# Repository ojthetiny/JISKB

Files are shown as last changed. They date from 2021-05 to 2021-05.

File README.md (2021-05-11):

# JISKB

Layout by the ever so wonderful Tesla

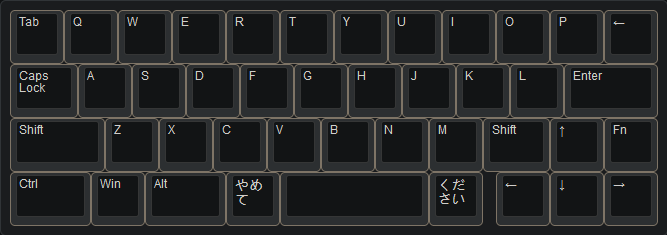
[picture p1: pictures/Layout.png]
Layout by the ever so wonderful Tesla


don't ask me what the fuck this is or why it exists, not my idea.
it's a jis hhkb 35% board or something, I was bored OK

pics of the fancy routing or whatever
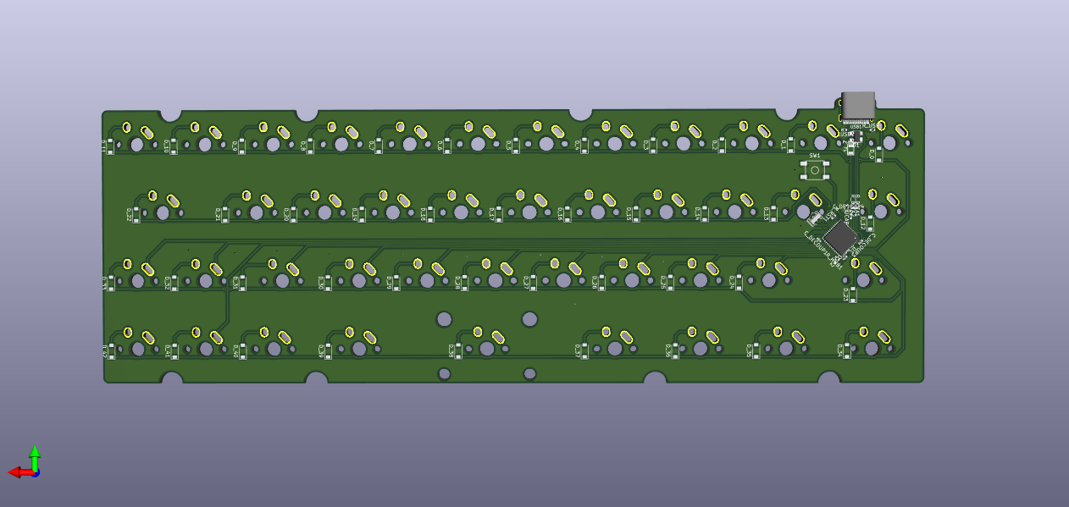
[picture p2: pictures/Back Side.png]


pics of the front if you give a shit, you probably don't
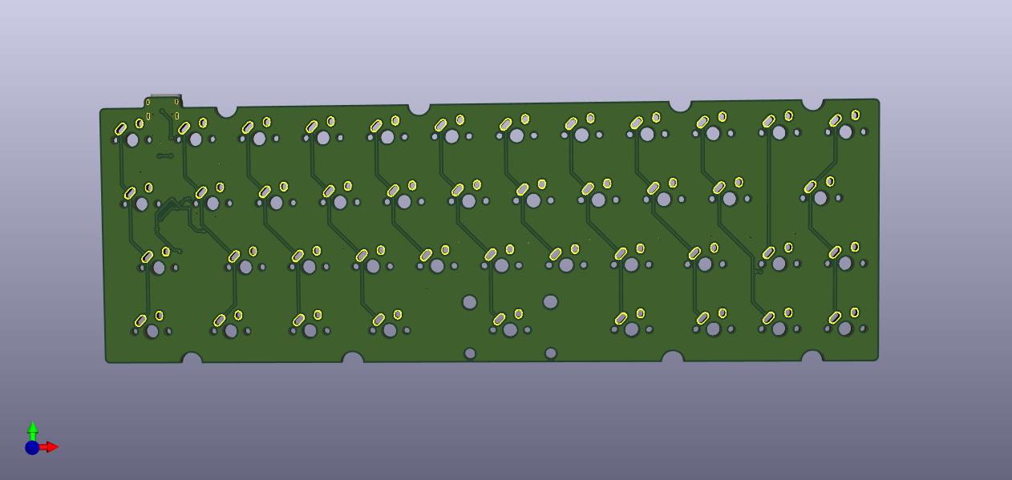
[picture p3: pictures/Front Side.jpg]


All the files are in the folders, including bom and pos files for assembly by jlc. if you wanna get this made you look for them yourself, I'm not helping you, use your noggin'

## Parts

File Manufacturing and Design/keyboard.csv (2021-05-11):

Comment | Designator | Footprint | LCSC
.1u | C_DECOUP1,C_DECOUP2,C_DECOUP3 | Capacitor_SMD:C_0402_1005Metric | C1525
10u | C_DECOUP4 | Capacitor_SMD:C_0402_1005Metric | C15525
1u | C_UCAP1 | Capacitor_SMD:C_0402_1005Metric | C107372
PRTR5V0U2X | D1 | Package_TO_SOT_SMD:SOT-143 | C12333
D | D_0,D_1,D_2,D_3,D_4,D_5,D_6,D_7,D_8,D_9,D_10,D_11,D_12,D_13,D_14,D_15,D_16,D_17,D_18,D_19,D_20,D_21,D_22,D_23,D_24,D_25,D_26,D_27,D_28,D_29,D_30,D_31,D_32,D_33,D_34,D_35,D_36,D_37,D_38,D_39,D_40,D_41,D_42 | Diode_SMD:D_SOD-123 | C64898
Polyfuse | F1 | Components:Fuse_0805 | C261942
KEYSW | K_0,K_1,K_2,K_3,K_4,K_5,K_6,K_7,K_8,K_9,K_10,K_11,K_13,K_14,K_15,K_16,K_17,K_18,K_19,K_20,K_21,K_24,K_25,K_26,K_27,K_28,K_29,K_30,K_32,K_33,K_35,K_37,K_39,K_40,K_41,K_42 | MX_Alps_Hybrid:MX-1U-NoLED
KEYSW | K_12,K_31 | MX_Alps_Hybrid:MX-1.25U-NoLED
KEYSW | K_22,K_23 | MX_Alps_Hybrid:MX-1.75U-NoLED
KEYSW | K_34,K_36 | MX_Alps_Hybrid:MX-1.5U-NoLED
KEYSW | K_38 | MX_Alps_Hybrid:MX-2.75U-NoLED
22 | R_DATA1,R_DATA2 | Resistor_SMD:R_0402_1005Metric | C25092
10k | R_HWB1,R_RST1 | Resistor_SMD:R_0402_1005Metric | C25744
5k1 | R_USB1,R_USB2 | Resistor_SMD:R_0402_1005Metric | C25905
SW_Push | SW1 | Components:SKQG-1155865
ATmega32U4-M | U1 | Package_DFN_QFN:QFN-44-1EP_7x7mm_P0.5mm_EP5.2x5.2mm | C112161
HRO-TYPE-C-31-M-12 | USB1 | Components:HRO-TYPE-C-31-M-12-Assembly | C165948
Resonator_Small | Y1 | Crystal:Resonator_SMD_Murata_CSTxExxV-3Pin_3.0x1.1mm | C341521

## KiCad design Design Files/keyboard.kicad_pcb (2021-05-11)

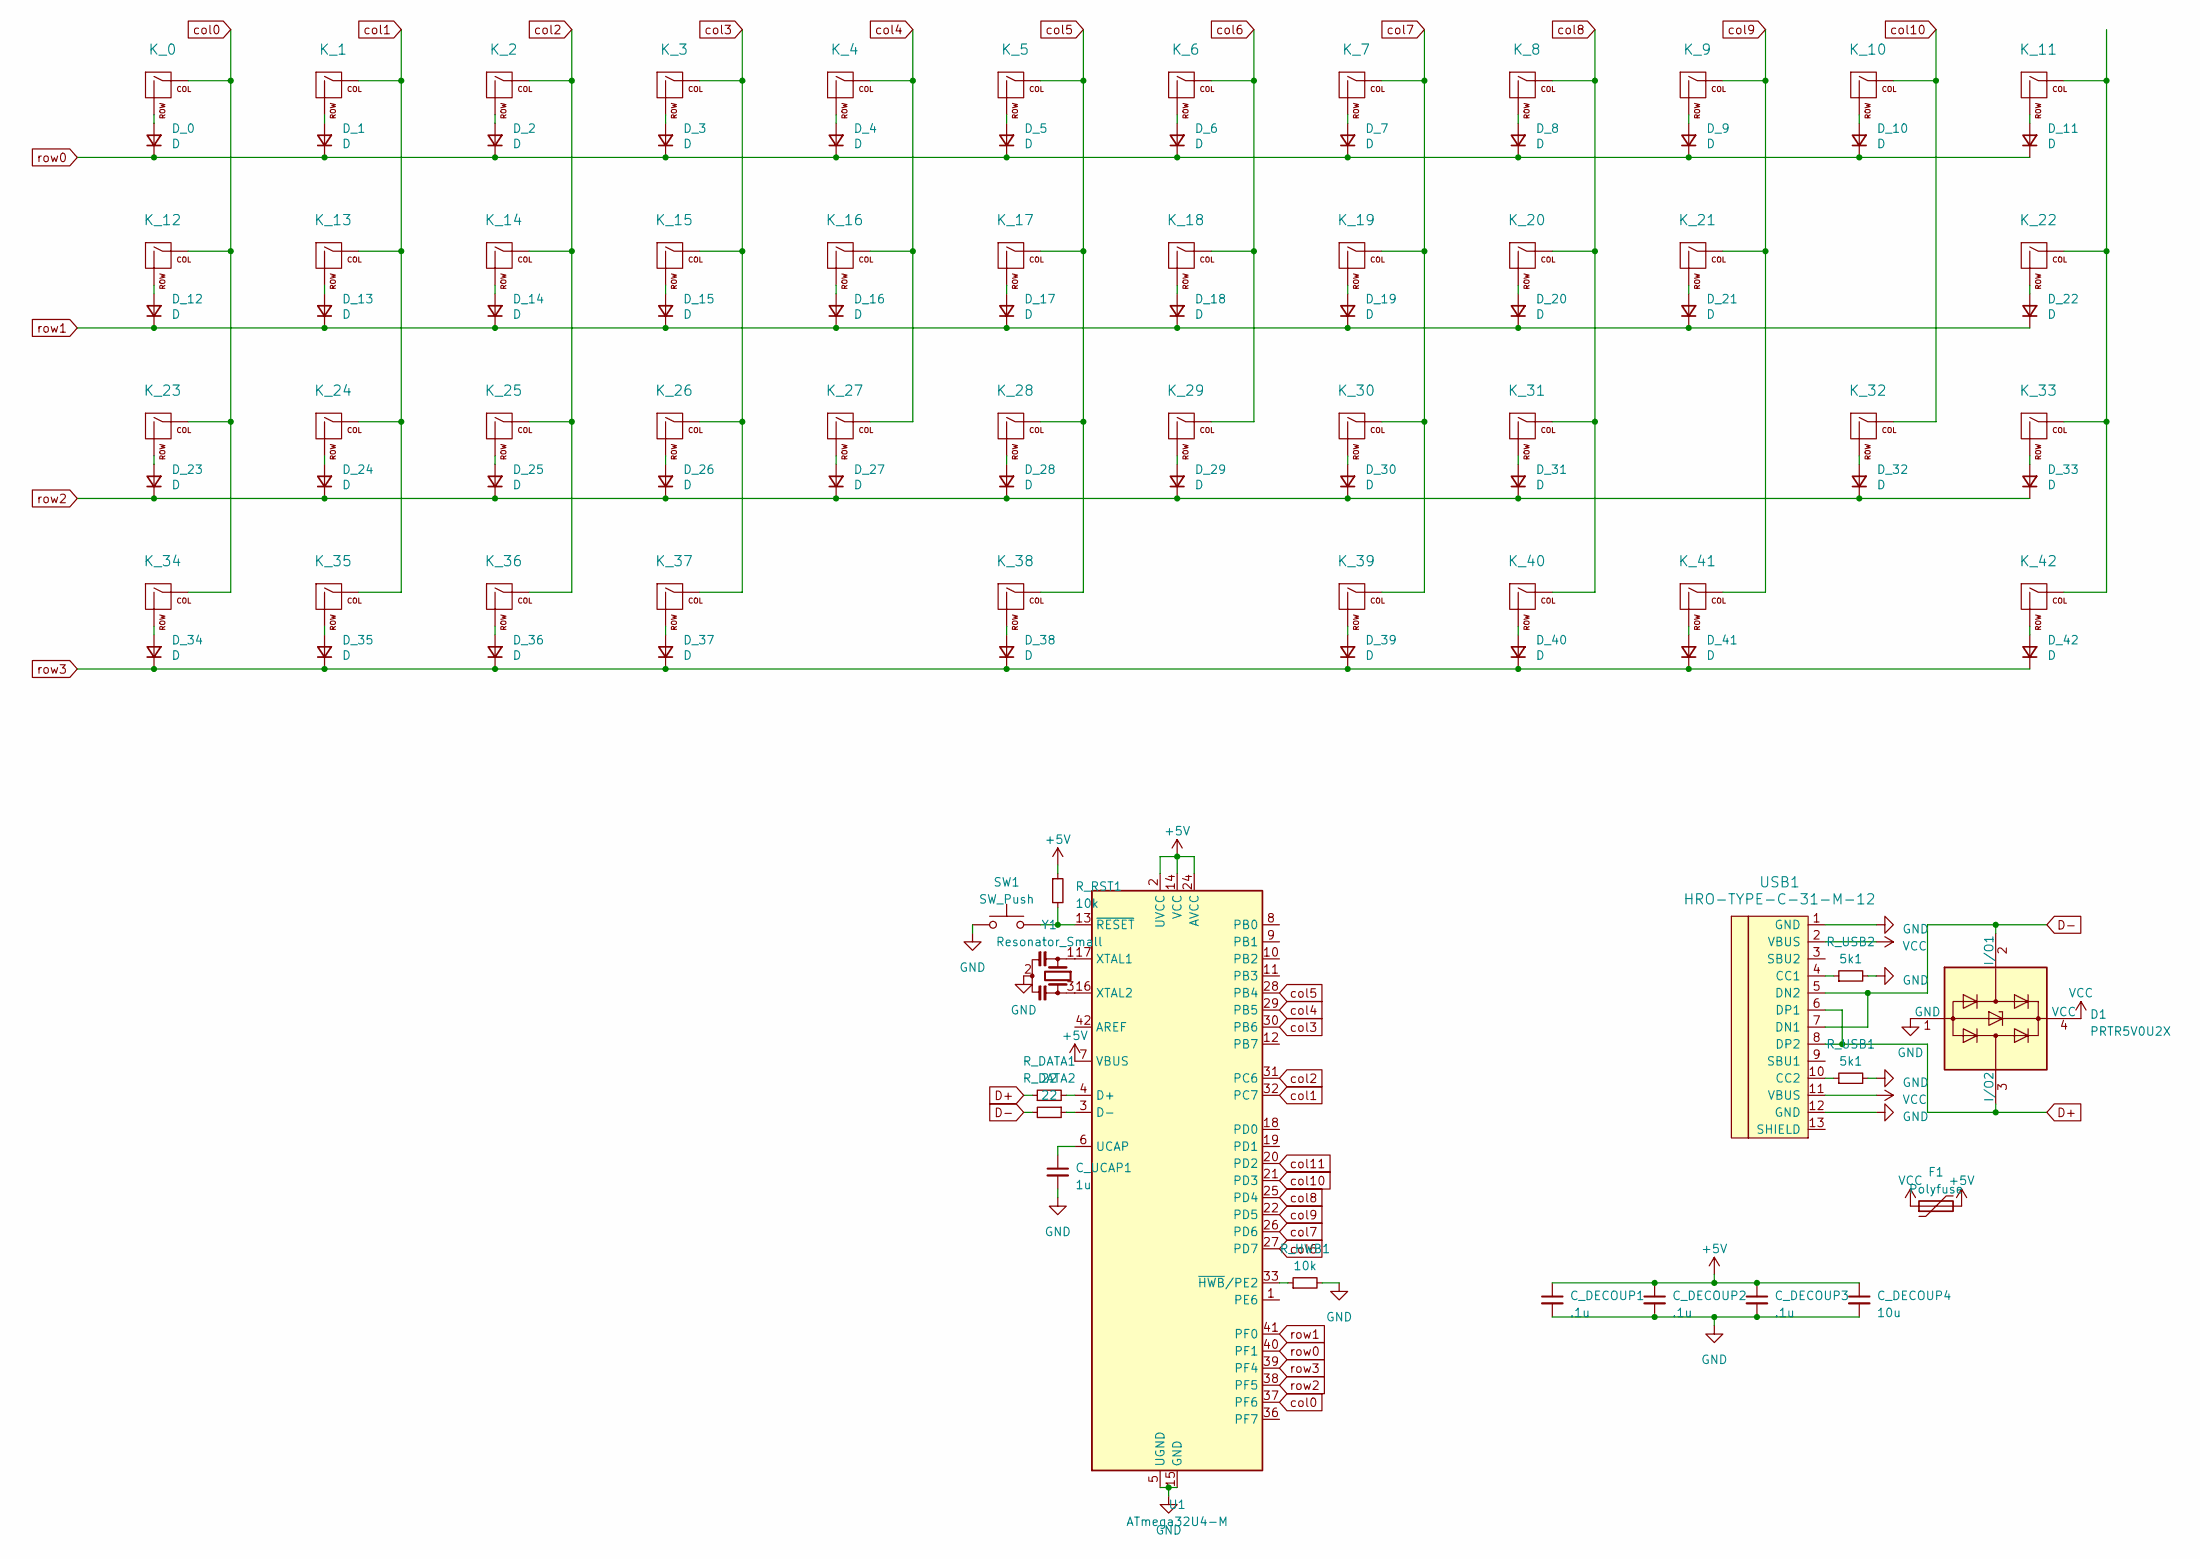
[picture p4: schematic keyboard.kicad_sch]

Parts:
C_DECOUP1, C_DECOUP2, C_DECOUP3: .1u; C_0402_1005Metric
C_DECOUP4: 10u; C_0402_1005Metric
C_UCAP1: 1u; C_0402_1005Metric
D1: PRTR5V0U2X; SOT-143
D_0, D_1, D_2, D_3, D_4, D_5, D_6, D_7, D_8, D_9, D_10, D_11, D_12, D_13, D_14, D_15, D_16, D_17, D_18, D_19, D_20, D_21, D_22, D_23, D_24, D_25, D_26, D_27, D_28, D_29, D_30, D_31, D_32, D_33, D_34, D_35, D_36, D_37, D_38, D_39, D_40, D_41, D_42: D; D_SOD-123
F1: Polyfuse; Fuse_0805
K_0, K_1, K_2, K_3, K_4, K_5, K_6, K_7, K_8, K_9, K_10, K_11, K_13, K_14, K_15, K_16, K_17, K_18, K_19, K_20, K_21, K_24, K_25, K_26, K_27, K_28, K_29, K_30, K_32, K_33, K_35, K_37, K_39, K_40, K_41, K_42: KEYSW; MX-1U-NoLED
K_12, K_31: KEYSW; MX-1.25U-NoLED
K_22, K_23: KEYSW; MX-1.75U-NoLED
K_34, K_36: KEYSW; MX-1.5U-NoLED
K_38: KEYSW; MX-2.75U-NoLED
R_DATA1, R_DATA2: 22; R_0402_1005Metric
R_HWB1: 10k; R_0402_1005Metric
R_RST1: 10k; R_0402_1005Metric
R_USB1, R_USB2: 5k1; R_0402_1005Metric
SW1: SW_Push; SKQG-1155865
U1: ATmega32U4-M; QFN-44-1EP_7x7mm_P0.5mm_EP5.2x5.2mm
USB1: HRO-TYPE-C-31-M-12; HRO-TYPE-C-31-M-12-Assembly
Y1: Resonator_Small; Resonator_SMD_Murata_CSTxExxV-3Pin_3.0x1.1mm

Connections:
+5V: C_DECOUP1.1, C_DECOUP2.1, C_DECOUP3.1, C_DECOUP4.1, F1.2, R_RST1.1, U1.2 (UVCC), U1.7 (VBUS), U1.14 (VCC), U1.24 (AVCC), U1.34 (VCC), U1.44 (AVCC)
D+: D1.3 (I/O2), R_DATA1.1, USB1.6 (DP1), USB1.8 (DP2)
D-: D1.2 (I/O1), R_DATA2.2, USB1.5 (DN2), USB1.7 (DN1)
GND: C_DECOUP1.2, C_DECOUP2.2, C_DECOUP3.2, C_DECOUP4.2, C_UCAP1.2, D1.1 (GND), R_HWB1.2, R_USB1.2, R_USB2.2, SW1.1, U1.5 (UGND), U1.15 (GND), U1.23 (GND), U1.35 (GND), U1.43 (GND), U1.45 (GND), USB1.1 (GND), USB1.12 (GND), Y1.2
unnamed: C_UCAP1.1, U1.6 (UCAP)
unnamed: D_0.2 (A), K_0.2 (ROW)
unnamed: D_1.2 (A), K_1.2 (ROW)
unnamed: D_2.2 (A), K_2.2 (ROW)
unnamed: D_3.2 (A), K_3.2 (ROW)
unnamed: D_4.2 (A), K_4.2 (ROW)
unnamed: D_5.2 (A), K_5.2 (ROW)
unnamed: D_6.2 (A), K_6.2 (ROW)
unnamed: D_7.2 (A), K_7.2 (ROW)
unnamed: D_8.2 (A), K_8.2 (ROW)
unnamed: D_9.2 (A), K_9.2 (ROW)
unnamed: D_10.2 (A), K_10.2 (ROW)
unnamed: D_11.2 (A), K_11.2 (ROW)
unnamed: D_12.2 (A), K_12.2 (ROW)
unnamed: D_13.2 (A), K_13.2 (ROW)
unnamed: D_14.2 (A), K_14.2 (ROW)
unnamed: D_15.2 (A), K_15.2 (ROW)
unnamed: D_16.2 (A), K_16.2 (ROW)
unnamed: D_17.2 (A), K_17.2 (ROW)
unnamed: D_18.2 (A), K_18.2 (ROW)
unnamed: D_19.2 (A), K_19.2 (ROW)
unnamed: D_20.2 (A), K_20.2 (ROW)
unnamed: D_21.2 (A), K_21.2 (ROW)
unnamed: D_22.2 (A), K_22.2 (ROW)
unnamed: D_23.2 (A), K_23.2 (ROW)
unnamed: D_24.2 (A), K_24.2 (ROW)
unnamed: D_25.2 (A), K_25.2 (ROW)
unnamed: D_26.2 (A), K_26.2 (ROW)
unnamed: D_27.2 (A), K_27.2 (ROW)
unnamed: D_28.2 (A), K_28.2 (ROW)
unnamed: D_29.2 (A), K_29.2 (ROW)
unnamed: D_30.2 (A), K_30.2 (ROW)
unnamed: D_31.2 (A), K_31.2 (ROW)
unnamed: D_32.2 (A), K_32.2 (ROW)
unnamed: D_33.2 (A), K_33.2 (ROW)
unnamed: D_34.2 (A), K_34.2 (ROW)
unnamed: D_35.2 (A), K_35.2 (ROW)
unnamed: D_36.2 (A), K_36.2 (ROW)
unnamed: D_37.2 (A), K_37.2 (ROW)
unnamed: D_38.2 (A), K_38.2 (ROW)
unnamed: D_39.2 (A), K_39.2 (ROW)
unnamed: D_40.2 (A), K_40.2 (ROW)
unnamed: D_41.2 (A), K_41.2 (ROW)
unnamed: D_42.2 (A), K_42.2 (ROW)
unnamed: R_DATA1.2, U1.4 (D+)
unnamed: R_DATA2.1, U1.3 (D-)
unnamed: R_HWB1.1, U1.33 (~HWB~/PE2)
unnamed: R_RST1.2, SW1.2, U1.13 (~RESET)
unnamed: R_USB1.1, USB1.10 (CC2)
unnamed: R_USB2.1, USB1.4 (CC1)
unnamed: U1.16 (XTAL2), Y1.3
unnamed: U1.17 (XTAL1), Y1.1
VCC: D1.4 (VCC), F1.1, USB1.2 (VBUS), USB1.11 (VBUS)
col0: K_0.1 (COL), K_12.1 (COL), K_23.1 (COL), K_34.1 (COL), U1.37 (PF6)
col1: K_1.1 (COL), K_13.1 (COL), K_24.1 (COL), K_35.1 (COL), U1.32 (PC7)
col2: K_2.1 (COL), K_14.1 (COL), K_25.1 (COL), K_36.1 (COL), U1.31 (PC6)
col3: K_3.1 (COL), K_15.1 (COL), K_26.1 (COL), K_37.1 (COL), U1.30 (PB6)
col4: K_4.1 (COL), K_16.1 (COL), K_27.1 (COL), U1.29 (PB5)
col5: K_5.1 (COL), K_17.1 (COL), K_28.1 (COL), K_38.1 (COL), U1.28 (PB4)
col6: K_6.1 (COL), K_18.1 (COL), K_29.1 (COL), U1.27 (PD7)
col7: K_7.1 (COL), K_19.1 (COL), K_30.1 (COL), K_39.1 (COL), U1.26 (PD6)
col8: K_8.1 (COL), K_20.1 (COL), K_31.1 (COL), K_40.1 (COL), U1.25 (PD4)
col9: K_9.1 (COL), K_21.1 (COL), K_41.1 (COL), U1.22 (PD5)
col10: K_10.1 (COL), K_32.1 (COL), U1.21 (PD3)
row0: D_0.1 (K), D_1.1 (K), D_2.1 (K), D_3.1 (K), D_4.1 (K), D_5.1 (K), D_6.1 (K), D_7.1 (K), D_8.1 (K), D_9.1 (K), D_10.1 (K), D_11.1 (K), U1.40 (PF1)
row1: D_12.1 (K), D_13.1 (K), D_14.1 (K), D_15.1 (K), D_16.1 (K), D_17.1 (K), D_18.1 (K), D_19.1 (K), D_20.1 (K), D_21.1 (K), D_22.1 (K), U1.41 (PF0)
row2: D_23.1 (K), D_24.1 (K), D_25.1 (K), D_26.1 (K), D_27.1 (K), D_28.1 (K), D_29.1 (K), D_30.1 (K), D_31.1 (K), D_32.1 (K), D_33.1 (K), U1.38 (PF5)
row3: D_34.1 (K), D_35.1 (K), D_36.1 (K), D_37.1 (K), D_38.1 (K), D_39.1 (K), D_40.1 (K), D_41.1 (K), D_42.1 (K), U1.39 (PF4)

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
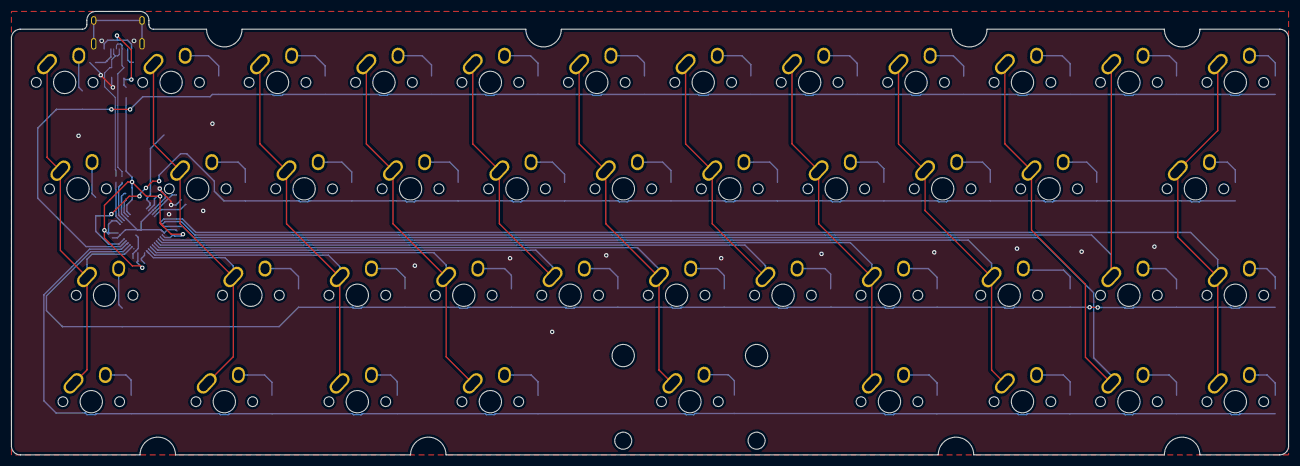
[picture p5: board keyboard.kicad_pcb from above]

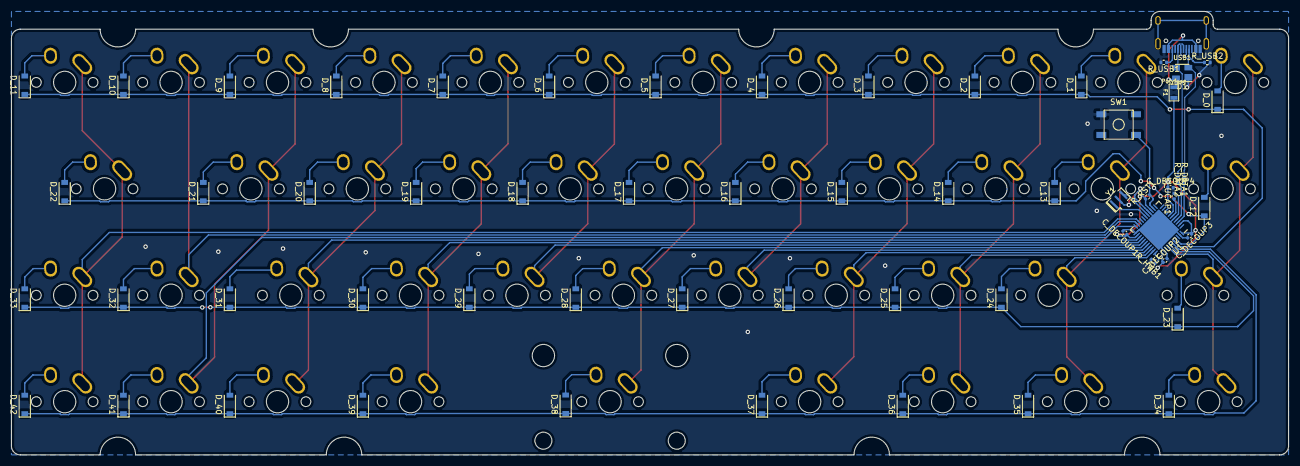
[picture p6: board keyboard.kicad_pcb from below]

Board: 2 copper layers, 228.6 x 79.4 mm, 103 parts (60 on the bottom side), 73 nets.
